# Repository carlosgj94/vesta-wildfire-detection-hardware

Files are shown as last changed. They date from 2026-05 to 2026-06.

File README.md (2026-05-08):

# Vesta Fire Detector

Vesta is an early-stage project to build an open source hardware device for
wildfire detection. The hardware design is being done in KiCad, with the goal
of making a device that is easy to manufacture, cheap to deploy, and reliable
in harsh outdoor environments.

The device is intended to detect local environmental changes that may indicate
wildfire risk or an active fire, then report them as early as possible.

## Schematic

Vesta schematic

## Current Hardware

The current KiCad schematic includes:

- `STM32WL55CCU6`: main low-power microcontroller and wireless reporting
  platform.
- `BQ24074RGTR`: lithium battery charger and power-path management IC.
- `TPS63900DSKR`: efficient buck-boost regulator for the system supply.
- Solar panel inputs and battery connector for field power.
- Crystals, TVS protection, test points, jumpers, and passive support circuitry.

The current sensor set is:

- `BME688`: environmental sensor used for temperature, humidity, pressure, and
  gas/air-quality signals that can help identify smoke or fire-related changes.
- `SHT40-AD1F-R2`: temperature and humidity sensor used for accurate local
  climate readings and cross-checking the environmental baseline.

## Status

The project is still early stage. Full schematics should be ready soon, then the
work will move to PCB layout and 3D CAD. Embedded OS software will be provided
last, once the hardware platform is stable.

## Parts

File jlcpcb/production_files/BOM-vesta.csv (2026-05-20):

Comment | Designator | Footprint | LCSC | Quantity
0kΩ | R14,R9 | R_0603 | C21189 | 2
0Ω | R13 | R_0402 | C17168 | 1
100kΩ | R11 | R_0402 | C25741 | 1
100kΩ | R12,R4,R5,R6 | R_0603 | C25803 | 4
100nF | C10,C11,C12,C13,C15,C19,C2,C22,C23 | C_0603 | C14663 | 9
100pF | C16,C17,C18 | C_0402 | C1546 | 3
10kΩ | R15,R16,R3 | R_0603 | C25804 | 3
10nF | C9 | C_0603 | C57112 | 1
10uF | C1,C3,C4,C5 | C_0805_2012Metric | C15850 | 4
16.2kΩ | R8 | R_0603 | C2933154 | 1
1uF | C8 | C_0603 | C15849 | 1
22uF | C6 | C_0805 | C45783 | 1
36.5kΩ | R10 | R_0603 | C2930095 | 1
4.7uF | C14 | C_0805 | C1779 | 1
470nF | C7 | C_0603 | C1623 | 1
68kΩ | R7 | R_0603 | C23231 | 1
7.87kΩ | R1 | R_0603 | C2930129 | 1
8.87kΩ | R2 | R_0603 | C2998144 | 1
BALFHB-WL-05D3 | FL1 | BALFHB-WL-05D3 | C5350080 | 1
BME688_C3664478 | U4 | BME688_C3664478 | C3664478 | 1
BQ24074RGTR | U2 | BQ24074RGTR | C54313 | 1
Conn_01x03 | U.FL1 | IPEX-SMD_BWIPX-1-001E | C496552 | 1
D_TVS | D1 | D_SOD-123 | C52148347 | 1
FNR5040S150MT | L3 | FNR5040S150MT | C167969 | 1
FTC252012S2R2MBCA | L1 | FTC252012S2R2MBCA | C5832372 | 1
PE4259-63 | U6 | PE4259-63 | C470892 | 1
Q13FC1350000400 | X1 | FC-135R_L3.2-W1.5 | C32346 | 1
STM32WL55CCU6 | U1 | STM32WL55CCU6 | C5270474 | 1
Solar Panel | J1,J2 | WAFER-PH2_0-2PWZ | C5359610 | 2
TPS63900DSKR | U3 | TPS63900DSKR | C1518762 | 1
WAFER-PH2_0-2PWZ | BATTERY1 | WAFER-PH2_0-2PWZ | C5359610 | 1
X201632MMB4SI | X2 | X201632MMB4SI | C383840 | 1
Conn_01x10 | J_EXP1 | PinHeader_1x10_P2.00mm_Vertical |  | 1

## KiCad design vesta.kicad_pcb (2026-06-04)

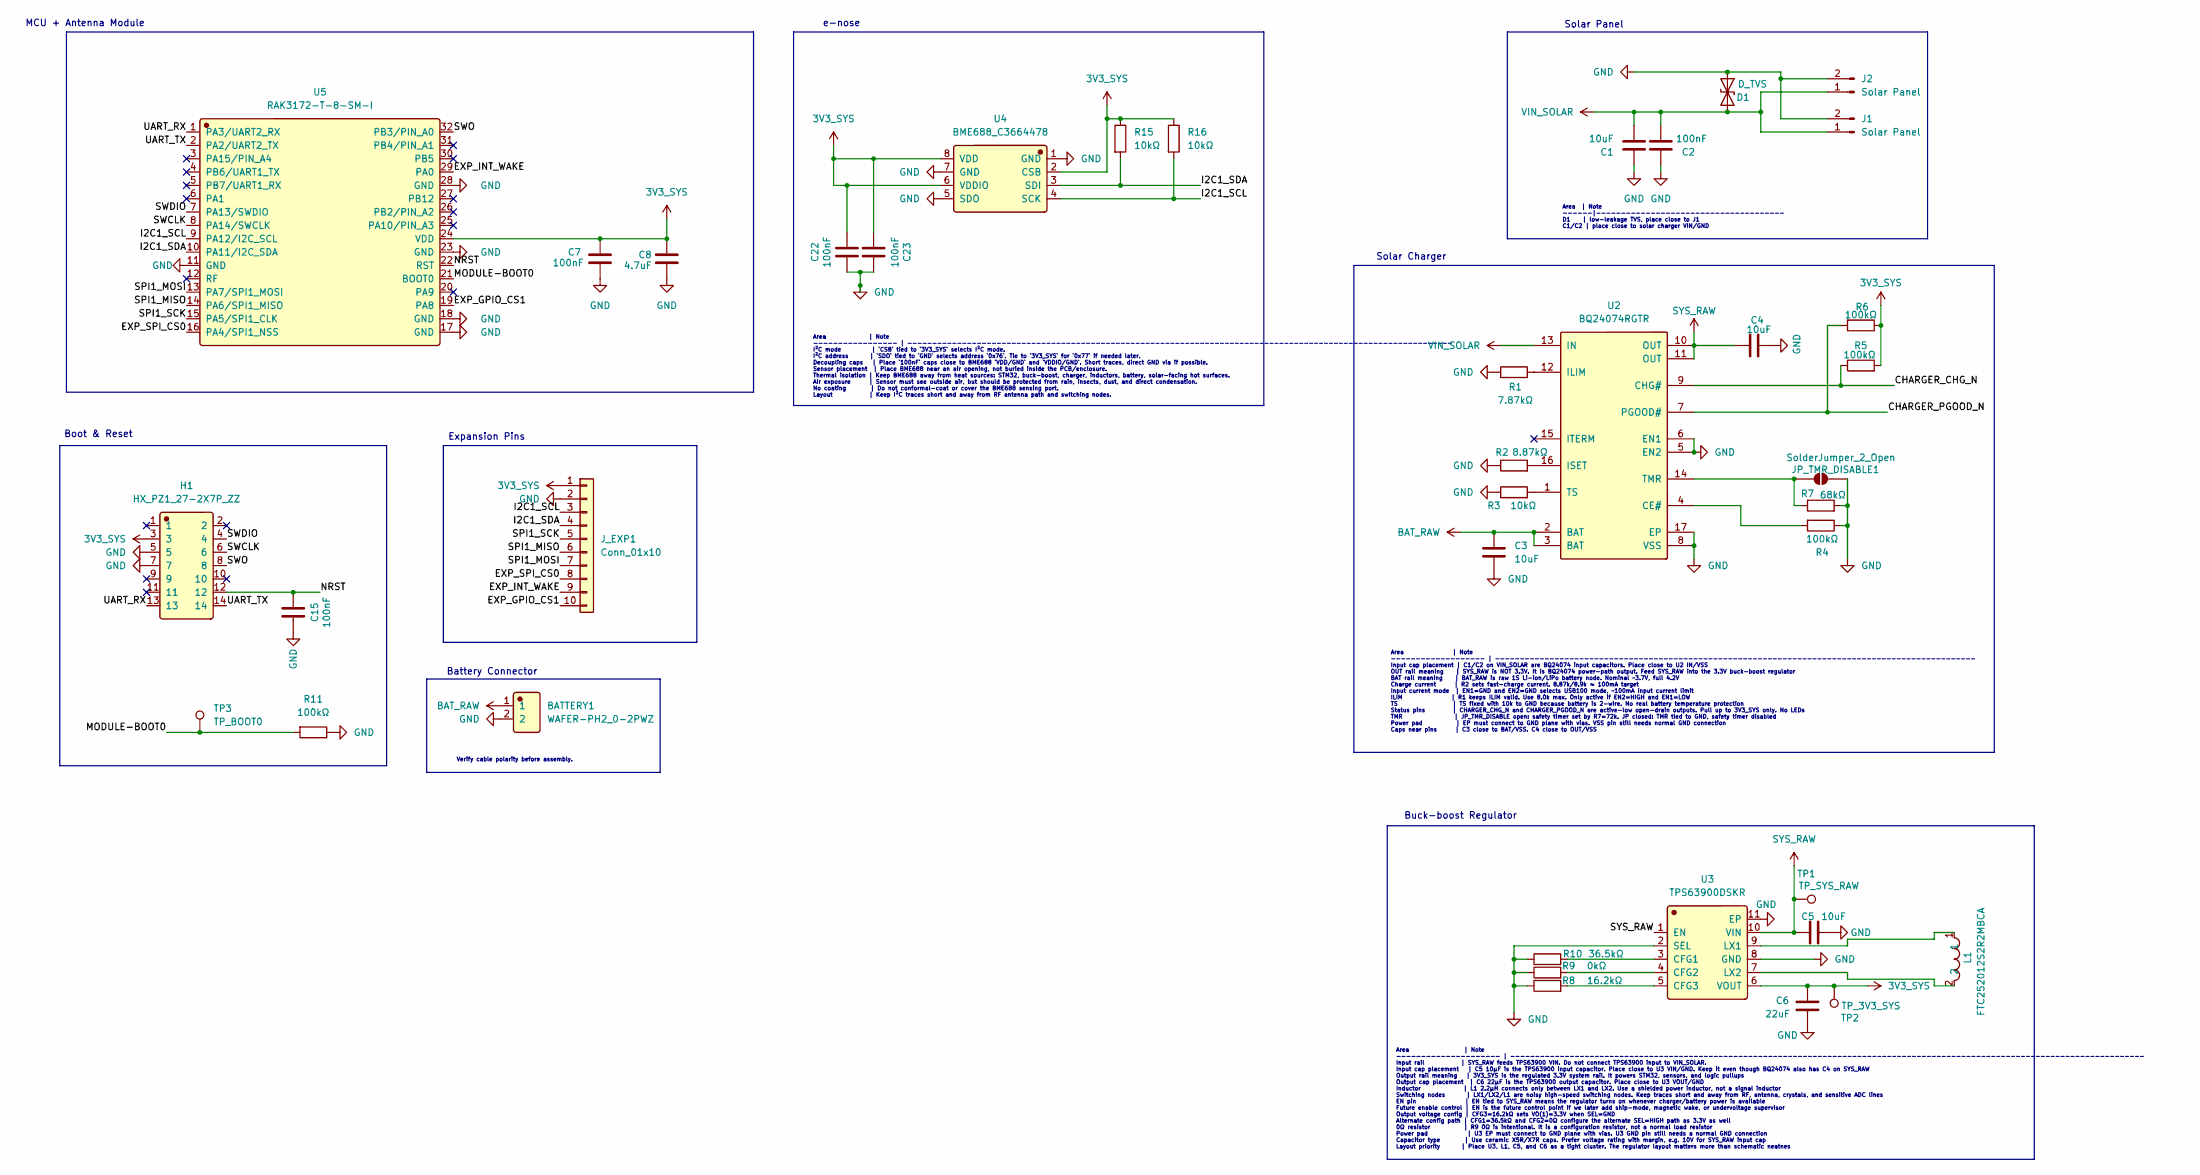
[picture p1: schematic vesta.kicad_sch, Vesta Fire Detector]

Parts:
BATTERY1: WAFER-PH2_0-2PWZ; Manufacturer Part WAFER-PH2.0-2PWZ; LCSC C5359610
C1: 10uF; C_0805_2012Metric
C2: 100nF; C_0603_1608Metric
C3, C4, C5: 10uF; C_0805
C6: 22uF; C_0805
C7, C15, C22, C23: 100nF; C_0402_1005Metric
C8: 4.7uF; C_0805_2012Metric
D1: D_TVS; D_SOD-123
H1: HX_PZ1_27-2X7P_ZZ; Manufacturer Part HX PZ1.27-2x7P ZZ; LCSC C22438122
J1, J2: Solar Panel; WAFER-PH2_0-2PWZ
JP_TMR_DISABLE1: SolderJumper_2_Open; SolderJumper-2_P1.3mm_Open_RoundedPad1.0x1.5mm
J_EXP1: Conn_01x10; PinHeader_1x10_P2.00mm_Vertical
L1: FTC252012S2R2MBCA; Manufacturer Part FTC252012S2R2MBCA; LCSC C5832372
R1: 7.87kΩ; R_0603
R2: 8.87kΩ; R_0603
R3, R15, R16: 10kΩ; R_0603
R4, R5, R6: 100kΩ; R_0603
R7: 68kΩ; R_0603
R8: 16.2kΩ; R_0603
R9: 0kΩ; R_0603
R10: 36.5kΩ; R_0603
R11: 100kΩ; R_0402
TP1: TP_SYS_RAW; TestPoint_Pad_D1.5mm
TP2: TP_3V3_SYS; TestPoint_Pad_D1.0mm
TP3: TP_BOOT0; TestPoint_Pad_D1.0mm
U2: BQ24074RGTR; Manufacturer Part BQ24074RGTR; LCSC C54313
U3: TPS63900DSKR; Manufacturer Part TPS63900DSKR; LCSC C1518762
U4: BME688_C3664478; Manufacturer Part BME688; LCSC C3664478
U5: RAK3172-T-8-SM-I; Manufacturer Part RAK3172-T-8-SM-I; LCSC C19723908

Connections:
3V3_SYS: C6.2, C7.2, C8.2, C22.2, C23.2, H1.3, J_EXP1.1, R5.2, R6.1, R15.1, R16.1, TP2.1 (1_1), U3.6 (VOUT), U4.2 (CSB), U4.6 (VDDIO), U4.8 (VDD), U5.24 (VDD)
/CHARGER_CHG_N: R5.1, U2.9 (CHG#)
/CHARGER_PGOOD_N: R6.2, U2.7 (PGOOD#)
/EXP_GPIO_CS1: J_EXP1.10, U5.19 (PA8)
/EXP_INT_WAKE: J_EXP1.9, U5.29 (PA0)
/EXP_SPI_CS0: J_EXP1.8, U5.16 (PA4/SPI1_NSS)
/I2C1_SCL: J_EXP1.3, R16.2, U4.4 (SCK), U5.9 (PA12/I2C_SCL)
/I2C1_SDA: J_EXP1.4, R15.2, U4.3 (SDI), U5.10 (PA11/I2C_SDA)
/MODULE-BOOT0: R11.2, TP3.1 (1_1), U5.21 (BOOT0)
/NRST: C15.1, H1.12, U5.22 (RST)
/SPI1_MISO: J_EXP1.6, U5.14 (PA6/SPI1_MISO)
/SPI1_MOSI: J_EXP1.7, U5.13 (PA7/SPI1_MOSI)
/SPI1_SCK: J_EXP1.5, U5.15 (PA5/SPI1_CLK)
/SWCLK: H1.6, U5.8 (PA14/SWCLK)
/SWDIO: H1.4, U5.7 (PA13/SWDIO)
/SWO: H1.8, U5.32 (PB3/PIN_A0)
/UART_RX: H1.13, U5.1 (PA3/UART2_RX)
/UART_TX: H1.14, U5.2 (PA2/UART2_TX)
BAT_RAW: BATTERY1.1, C3.1, U2.2 (BAT), U2.3 (BAT)
GND: BATTERY1.2, C1.1, C2.1, C3.2, C4.1, C5.1, C6.1, C7.1, C8.1, C15.2, C22.1, C23.1, D1.1 (A1), H1.5, H1.7, J1.2, J2.2, JP_TMR_DISABLE1.2 (B), J_EXP1.2, R1.1, R2.1, R3.1, R4.1, R7.2, R8.1, R9.1, R10.1, R11.1, U2.5 (EN2), U2.6 (EN1), U2.8 (VSS), U2.17 (EP), U3.2 (SEL), U3.8 (GND), U3.11 (EP), U4.1 (GND), U4.5 (SDO), U4.7 (GND), U5.11 (GND), U5.17 (GND), U5.18 (GND), U5.23 (GND), U5.28 (GND); also elsewhere on the board
unnamed 20: JP_TMR_DISABLE1.1 (A), R7.1, U2.14 (TMR); also elsewhere on the board
unnamed: R4.2, U2.4 (CE#)
unnamed: R1.2, U2.12 (ILIM)
unnamed: R2.2, U2.16 (ISET)
unnamed: R3.2, U2.1 (TS)
unnamed: R10.2, U3.3 (CFG1)
unnamed: R9.2, U3.4 (CFG2)
unnamed: R8.2, U3.5 (CFG3)
unnamed: L1.1, U3.9 (LX1)
unnamed: L1.2, U3.7 (LX2)
SYS_RAW: C4.2, C5.2, TP1.1 (1_1), U2.10 (OUT), U2.11 (OUT), U3.1 (EN), U3.10 (VIN)
VIN_SOLAR: C1.2, C2.2, D1.2 (A2), J1.1, J2.1, U2.13 (IN)

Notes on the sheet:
Expansion Pins
e-nose
Area | Note ----------------- | -------------------------------------------------------------------------------------------------------------- I²C mode | `CSB` tied to `3V3_SYS` selects I²C mode. I²C address | `SDO` tied to `GND` selects address `0x76`. Tie to `3V3_SYS` for `0x77` if needed later. 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
MCU + Antenna Module
Buck-boost Regulator
Area | Note --------------------- | -------------------------------------------------------------------------------------------------------------------------------- Input rail | SYS_RAW feeds TPS63900 VIN. Do not connect TPS63900 input to VIN_SOLAR. Input cap placement | C5 10µF is the TPS63900 inp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
Area | Note ------|-------------------------------------- D1 | low-leakage TVS, place close to J1 C1/C2 | place close to solar charger VIN/GND
Solar Charger
Boot & Reset
Verify cable polarity before assembly.
Battery Connector
Solar Panel
Area | Note ------------------- | ------------------------------------------------------------------------------------------------- Input cap placement | C1/C2 on VIN_SOLAR are BQ24074 input capacitors. Place close to U2 IN/VSS OUT rail meaning | SYS_RAW is NOT 3.3V. It is BQ24074 power-path output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

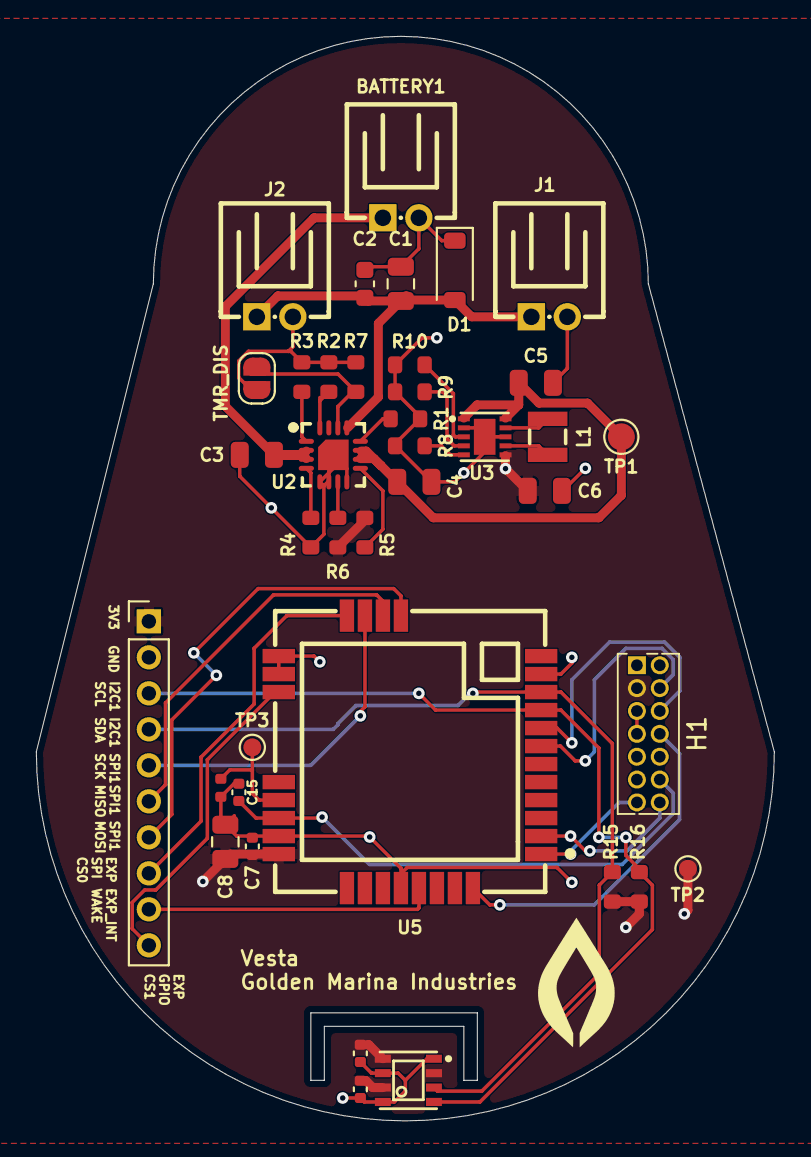
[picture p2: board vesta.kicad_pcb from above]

Board: 4 copper layers, 41.0 x 60.2 mm, 39 parts (0 on the bottom side), 32 nets.

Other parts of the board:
TMR_DIS: SolderJumper_2_Open; SolderJumper-2_P1.3mm_Open_RoundedPad1.0x1.5mm

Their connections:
GND: TMR_DIS.2 (B); also elsewhere on the board
unnamed 20: TMR_DIS.1 (A); also elsewhere on the board

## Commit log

2026-05-07 feat: initial setup of stm32 and power manangement
    [vesta.kicad_pcb, vesta.kicad_sch, vesta.sch]
2026-05-07 feat: adding the clocks, the boot and the reset to the schemas
    [vesta.kicad_sch]
2026-05-08 feat: adding the ST IPD and RF antenna
    [vesta.kicad_pcb, vesta.kicad_sch]
2026-05-08 feat: adding the connections to the sensor
    [vesta.kicad_sch]
2026-05-08 feat: adding the expansion pads
    [vesta.kicad_sch]
2026-05-08 chore: showing the schematics on the readme
2026-05-08 chore: saving backups
    [vesta.kicad_sch]
2026-05-09 feat: adding all the footprints
    [vesta.kicad_sch]
2026-05-09 feat: adding the components to the PCB
    [vesta.kicad_pcb]
2026-05-09 feat: making the pinecone
    [freerouting.dsn, temp-freerouting.dsn, vesta.kicad_pcb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]
2026-05-11 feat: updating the pins in the stm32 footprint
    [freerouting.dsn, temp-freerouting.dsn, vesta.kicad_pcb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]
2026-05-11 feat: created the nets
    [vesta.kicad_pcb]
2026-05-13 feat: doing all the critical connections
    [freerouting.dsn, temp-freerouting.dsn, vesta.kicad_pcb]
2026-05-13 feat: finishing all the connections
    [freerouting.dsn, temp-freerouting.dsn, vesta.kicad_pcb]
2026-05-13 feat: stabilize critical connections
    [freerouting.dsn, temp-freerouting.dsn, vesta.kicad_pcb]
2026-05-15 feat: improving the thermal dissipation of the sensor
    [vesta.kicad_pcb, vesta.kicad_sch]
2026-05-16 feat: updating the footprint of the antenna
    [vesta.kicad_pcb]
2026-05-19 feat: updating the references and adding the logo
    [vesta.kicad_pcb, vesta.kicad_sch]
2026-05-19 feat: updating footprints
    [vesta.kicad_pcb]
2026-05-19 feat: reverting the polarity on the batteries inputs
    [vesta.kicad_pcb, vesta.kicad_sch]
2026-05-19 feat: updating the logo to be on the silkscreen
    [vesta.kicad_pcb]
2026-05-20 feat: updating the U.FL part number and generating the gerbers
    [BOM-vesta.csv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]
2026-06-01 feat: changing the MCU and antenna for a pre-certified module
    [vesta.kicad_sch]
2026-06-01 feat: adding the new components into the PCB
    [vesta.kicad_pcb, vesta.kicad_sch]
2026-06-02 feat: adding references to all components
    [vesta.kicad_pcb]
2026-06-02 feat: small footprint fixes before starting the routing
    [vesta.kicad_pcb, vesta.kicad_sch]
2026-06-02 feat: PCB design ready
    [freerouting.dsn, temp-freerouting.dsn, vesta.kicad_pcb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]
2026-06-02 feat: updaing the BOM and adding the STLINK connector
    [vesta.kicad_pcb, vesta.kicad_sch]
2026-06-04 chore: cleaning up the schematics
    [vesta.kicad_sch]
2026-06-04 feat: small improvements for second revision
    [vesta.kicad_pcb, vesta.kicad_sch]
